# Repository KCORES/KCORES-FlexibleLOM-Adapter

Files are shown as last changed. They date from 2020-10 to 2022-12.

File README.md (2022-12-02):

# KCORES-FlexibleLOM-Adapter

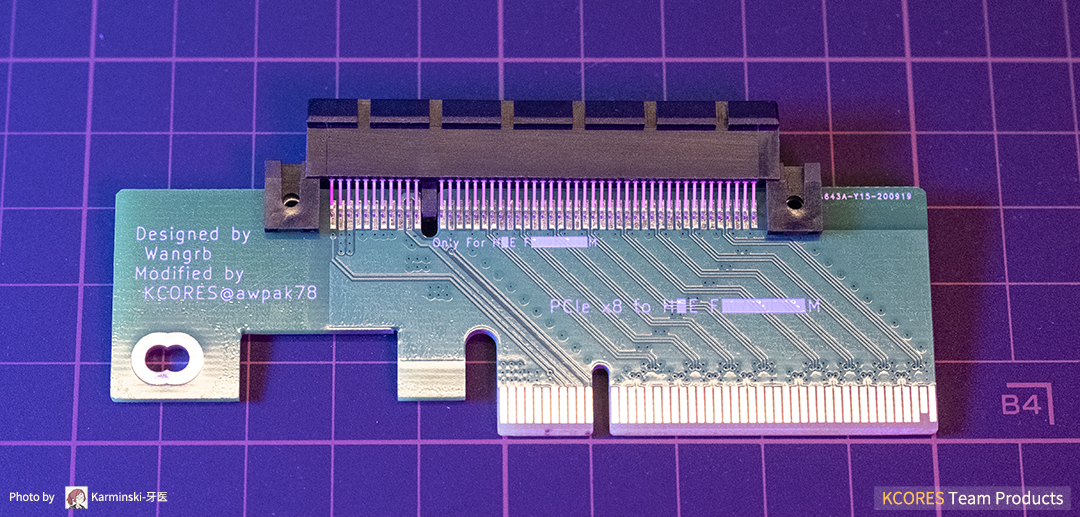
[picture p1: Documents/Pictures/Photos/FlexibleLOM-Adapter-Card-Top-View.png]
FlexibleLOM-Adapter-Card-Top-View
  

KCORES FlexibleLOM to PCIe x8 adapter and baffle model. The FLR series network cards can be used on normal motherboards PCIe slots, including common Gigabit, 10G, and 40G network cards. Due to size limitations, only full-height baffle design is available.  

KCORES FlexibleLOM 转 PCIe x8 转接卡开源设计，可以让普通电脑主板的 PCIe 槽使用 FLR 系列网卡，包括常见的千兆、万兆、40G网卡。由于尺寸限制，只提供全高挡板设计。

- 2 Layers PCB design, Easy to make  
双层PCB设计，容易制造

- Impedance matching by Polar SI9000  
使用 Polar SI9000 计算阻抗

- Size less than 10x10cm  
小尺寸，不超过 10x10cm

**[KCORES 官方网站](http://kcores.com/)**

**HomeLab 交流 QQ 群: 826702309**

# Compatibility

- ✔ Recommend 推荐
- 🟡 Compatible 兼容
- ❌ Fail 不兼容

| FlexibleLOM  | NIC Model | Connectors | [v1.0](https://github.com/KCORES/KCORES-FlexibleLOM-Adapter/releases/tag/v1.0) | v1.1 | SKU | SP | AS | Notes |
| --- | --- | --- | :----: | :----: | ---- | ---- | ---- | ---- |
| 331FLR | Broadcom BCM5719 | Quad RJ45 GbE | ❌ | ✔ | | | | 
| 366FLR | intel i350 | Quad RJ45 GbE | ✔ | ✔ | | | | 
| 530FLR-SFP+  | Broadcom BCM57810S | Dual SFP+ 10GbE | ❌ | ✔ | 647581-B21 | 649869-001 | 647579-001 |
| 533FLR-T | Broadcom BCM57810S | Dual RJ45 10GbE | ✔ | ✔ | 700759-B21 | 701534-001 | 700757-001 |
| 534FLR-SFP+  | Cavium BCM57810S | Dual SFP+ 10GbE | | | -B21 | -001 | -001 |
| 535FLR-T | Broadcom BCM57416 | Dual RJ45 10GbE | | | -B21 | -001 | -001 | RoCE V2, 15W |
| 536FLR-T | QLogic  57840S | Quad RJ45 10GbE | | | -B21 | -001 | -001 | 9W |
| 537FLR-SFP+  | Broadcom BCM57412 | Dual SFP+ 10GbE | | | -B21 | -001 | -001 | iWARP, 14W |
| ConnectX3ALOM| Mellanox ConnectX-3 | Single SFP+ 10GbE | | ✔ | 682148-B21 | 682625-001 | 682150-001 | 
| 544FLR-QSFP  | Mellanox ConnectX-3 | Dual QSFP+ 40GbE  | | | 649282-B21 | 656090-001 | 661686-001 |
| 544FLR-QSFP  | Mellanox ConnectX-3 | Dual QSFP+ 40GbE  | ✔ | ✔ | 649283-B21 | 656091-001 | 661687-001 |
| 544+FLR-SFP+ | Mellanox ConnectX-3 Pro | Single SFP+ 10GbE | ✔ | ✔ | 724206-B21 | 731850-001 | 724210-001 | 
| 544+FLR-QSFP | Mellanox ConnectX-3 Pro | Dual QSFP+ 40GbE  | ✔ | ✔ | 764285-B21 | 764737-001 | 764618-001 |
| 545FLR-QSFP  | Mellanox Connect-IB | Dual QSFP+ 56G IB | | | 7 -B21 | 7 -001 | 7 -001 |
| 546+FLR-SFP+ | Mellanox ConnectX-3 Pro | Dual SFP+ 10GbE | | | 779799-B21 | 7 -001 | 7 -001 |
| 547+FLR-QSFP | Mellanox ConnectX-5 | Dual QSFP+ 40GbE  | | | 879482-B21 | 8 -001 | 8 -001 |
| 554FLR-SFP+  | Emulex BE3 684213-B21 | Dual SFP+ 10GbE | | | 629142-B21 | 634026-001 | 629140-001 |
| 556FLR-T | Emulex XE-104 | Dual RJ45 10GbE | | | 794525-B21 | | | RoCE V1 |
| 556FLR-SFP+  | Emulex XE-102 727060-B21 | Dual SFP+ 10GbE | | | 732456-B21 | 764460-001 | 732454-001 | RoCE V1 |
| 560FLR-SFP+  | intel 82599 | Dual SFP+ 10GbE | ✔ | ✔ | | | | 
| 561FLR-T | intel X540 | Dual RJ45 10GbE | ✔ | ✔ | 700699-B21 | 701525-001 | 700697-001 |
| 562FLR-T | intel X550 | Dual RJ45 10GbE | ✔ | ✔ | 817745-B21 | 840138-001 | 817743 -001|
| 562FLR-SFP+  | intel X710 | Dual SFP+ 10GbE | | | 727054-B21 | 7 -001 | 7 -001 |
| 570FLR-SFP+  | SFC 9020 | Dual 10GbE | ✔ | ✔ | 717491-B21 | 717710-001 | 717489-001 | 

- **Note:**  
Some models of 544FLR-QSFP only support 10GbE and QDR. Please check
 the **Part Number** before buying!  
544FLR-QSFP 部分型号只支持 10GbE 和 QDR，请在购买前检查**物料号**！

# Directory

- /Documents/    
说明文档

- /Electricals/  
PCB design files  
3D 模型和挡板设计文件

- /Firmwares/  
Firmwares guide  
固件刷写相关教程

- /Mechanicals/  
FlexibleLOM Model and PCI Baffle  
FLR 卡模型及 PCI 挡板设计文件

# Photos & Renderings



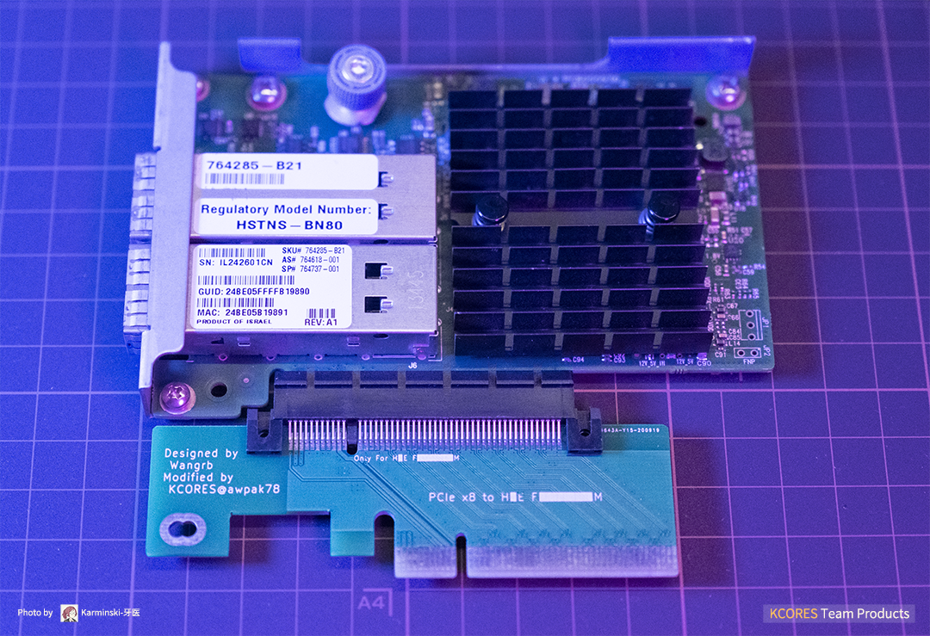
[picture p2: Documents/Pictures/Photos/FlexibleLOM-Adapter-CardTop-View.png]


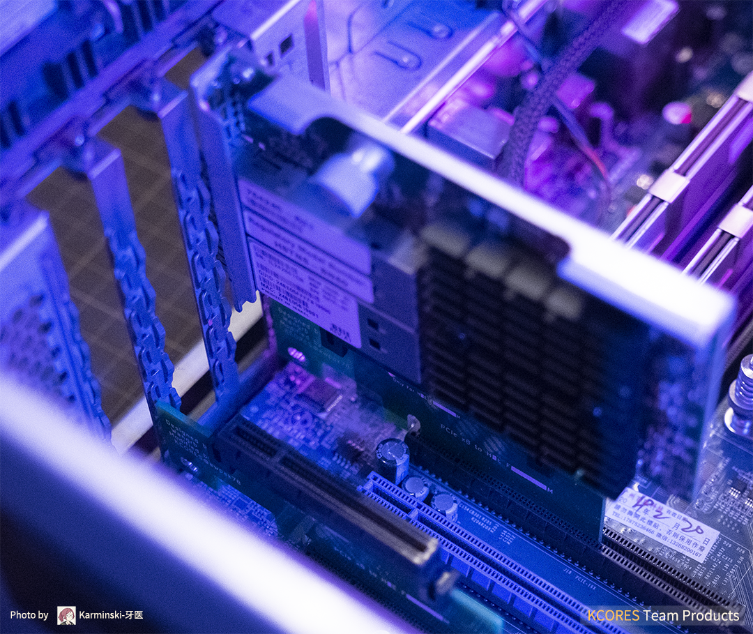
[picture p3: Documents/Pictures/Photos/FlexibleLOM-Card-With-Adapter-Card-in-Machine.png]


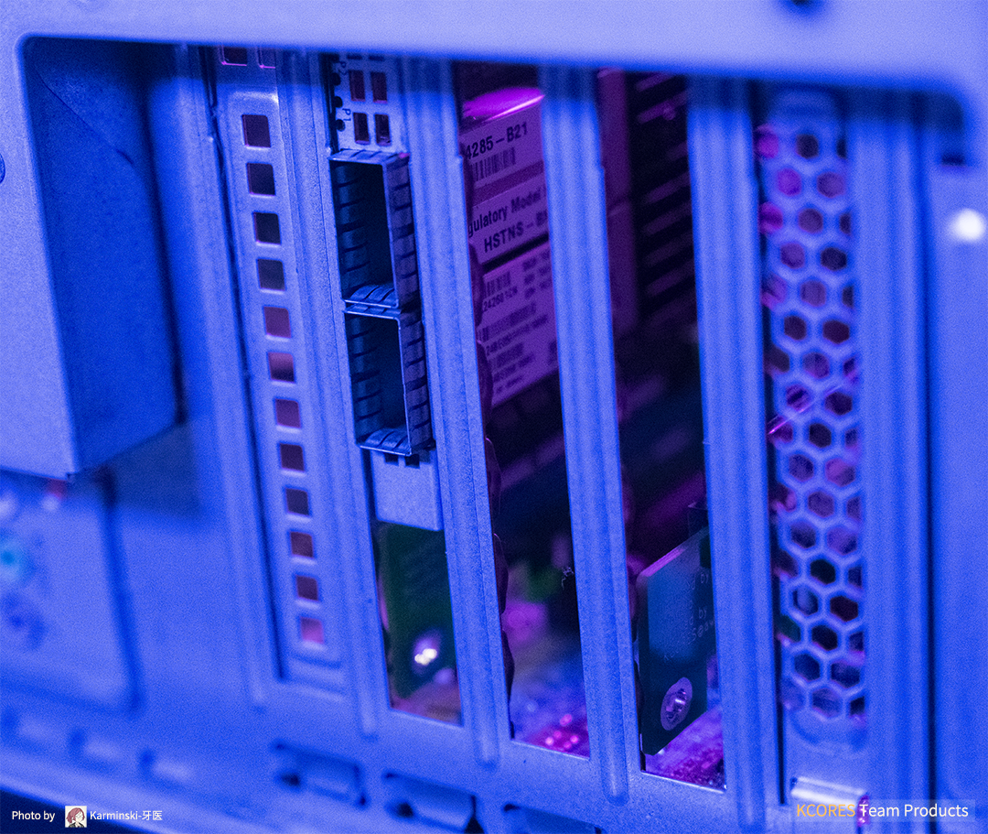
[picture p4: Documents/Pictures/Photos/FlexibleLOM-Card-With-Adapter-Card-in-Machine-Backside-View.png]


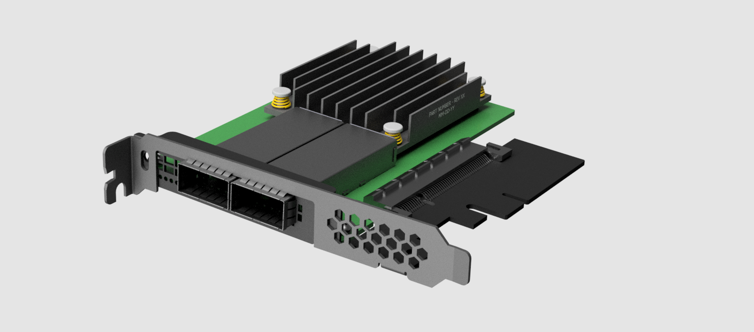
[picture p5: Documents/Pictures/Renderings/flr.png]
FlexibleLOM-Card-With-Adapter-Card-Renderings


# Thanks To

- [@Wangrb (Original Adapter Card Design)](https://github.com/Wangrb)
- [@AlphaArea (Main Contributer)](https://github.com/alphaarea)
- [@MistyMoonR (3D Model)](https://github.com/MistyMoonR)  
- [@Karminski (Photo)](https://github.com/karminski)

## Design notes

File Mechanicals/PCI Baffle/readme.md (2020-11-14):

# PCI Baffle

## Version: 1.0

- PCI Baffle Default  
  适合光口网卡  
  For SFP/QSFP Card  

- PCI Baffle RJ45  
  适合电口网卡   
  For RJ45 Crad

## Rendering   

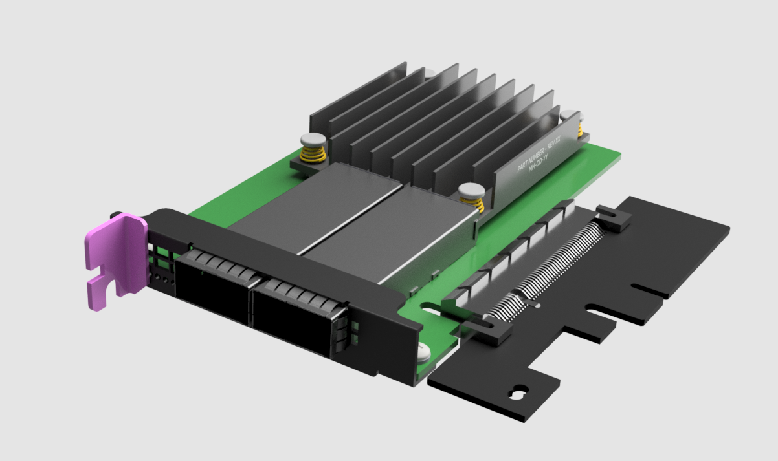
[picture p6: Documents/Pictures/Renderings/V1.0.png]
       

---

|Author |MistyMoon |
|--- |--- |
|E-mail |MistyMoonR@outlook.com |

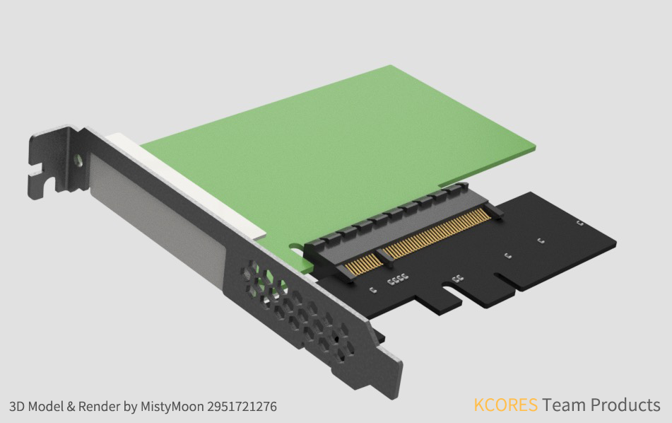
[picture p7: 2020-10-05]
Documents/Pictures/Photos/3D-Model.png

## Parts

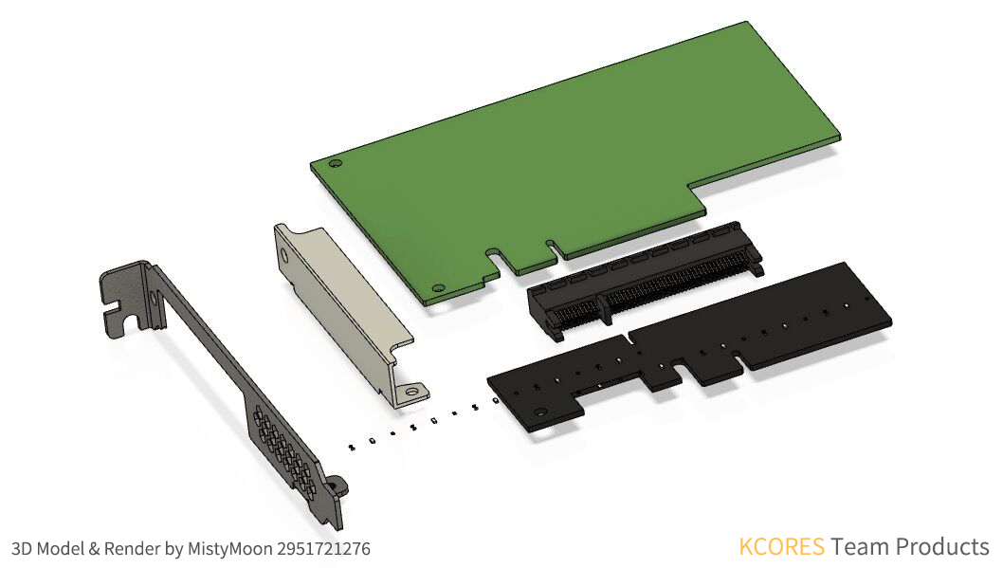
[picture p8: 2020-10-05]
Documents/Pictures/Photos/3D-Model-Parts.png

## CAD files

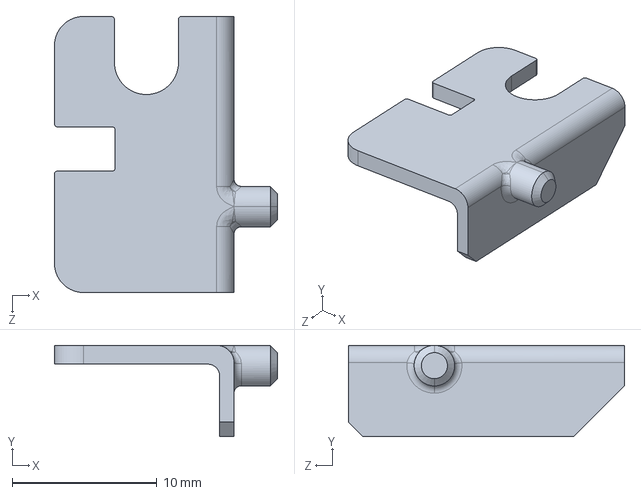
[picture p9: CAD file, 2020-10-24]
Mechanicals/PCI Baffle/PCI Baffle RJ45.STEP
15.4 x 6.30 x 19.1 mm

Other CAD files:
Mechanicals/PCI Baffle/PCI Baffle Default.STEP
Mechanicals/PCI Baffle/PCI Baffle Default.STL
Mechanicals/PCI Baffle/PCI Baffle RJ45.STL

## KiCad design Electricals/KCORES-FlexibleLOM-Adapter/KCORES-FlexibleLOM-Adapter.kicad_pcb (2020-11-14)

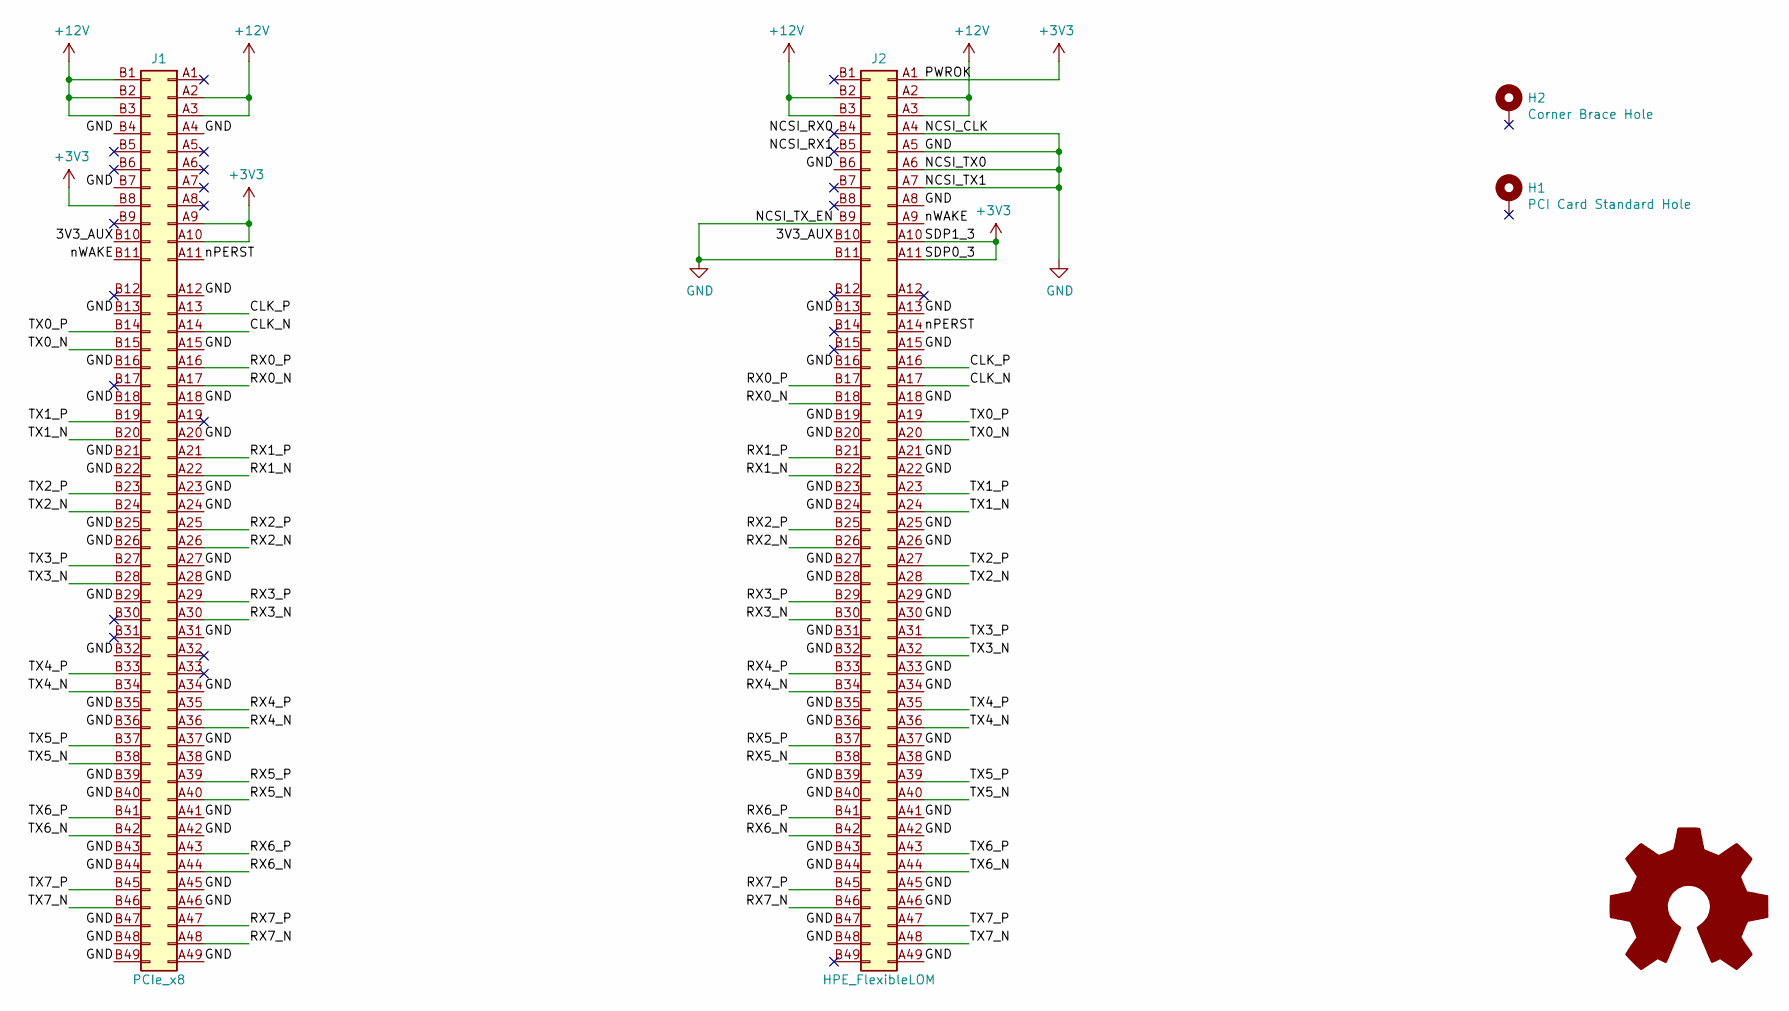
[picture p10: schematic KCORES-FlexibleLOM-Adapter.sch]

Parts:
H1: PCI Card Standard Hole; MountingHole_3.2mm_M3_Pad
H2: Corner Brace Hole; MountingHole_3.2mm_M3_Pad
J1: PCIe_x8; BUS_PCIexpress_x8
J2: HPE_FlexibleLOM; BUS_PCIexpress_x8_Straddle_Mount_Modify
LOGO1: Logo_Open_Hardware_Large; OSHW-Logo2_14.6x12mm_SilkScreen

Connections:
+3V3: J1.A9, J1.A10, J1.B8, J2.A1, J2.A10, J2.A11
+12V: J1.A2, J1.A3, J1.B1, J1.B2, J1.B3, J2.A2, J2.A3, J2.B2, J2.B3
/3V3_AUX: J1.B10, J2.B10
/CLK_N: J1.A14, J2.A17
/CLK_P: J1.A13, J2.A16
/NCSI_RX0: J2.B4
/NCSI_RX1: J2.B5
/RX0_N: J1.A17, J2.B18
/RX0_P: J1.A16, J2.B17
/RX1_N: J1.A22, J2.B22
/RX1_P: J1.A21, J2.B21
/RX2_N: J1.A26, J2.B26
/RX2_P: J1.A25, J2.B25
/RX3_N: J1.A30, J2.B30
/RX3_P: J1.A29, J2.B29
/RX4_N: J1.A36, J2.B34
/RX4_P: J1.A35, J2.B33
/RX5_N: J1.A40, J2.B38
/RX5_P: J1.A39, J2.B37
/RX6_N: J1.A44, J2.B42
/RX6_P: J1.A43, J2.B41
/RX7_N: J1.A48, J2.B46
/RX7_P: J1.A47, J2.B45
/TX0_N: J1.B15, J2.A20
/TX0_P: J1.B14, J2.A19
/TX1_N: J1.B20, J2.A24
/TX1_P: J1.B19, J2.A23
/TX2_N: J1.B24, J2.A28
/TX2_P: J1.B23, J2.A27
/TX3_N: J1.B28, J2.A32
/TX3_P: J1.B27, J2.A31
/TX4_N: J1.B34, J2.A36
/TX4_P: J1.B33, J2.A35
/TX5_N: J1.B38, J2.A40
/TX5_P: J1.B37, J2.A39
/TX6_N: J1.B42, J2.A44
/TX6_P: J1.B41, J2.A43
/TX7_N: J1.B46, J2.A48
/TX7_P: J1.B45, J2.A47
/nPERST: J1.A11, J2.A14
/nWAKE: J1.B11, J2.A9
GND: J1.A4, J1.A12, J1.A15, J1.A18, J1.A20, J1.A23, J1.A24, J1.A27, J1.A28, J1.A31, J1.A34, J1.A37, J1.A38, J1.A41, J1.A42, J1.A45, J1.A46, J1.A49, J1.B4, J1.B7, J1.B13, J1.B16, J1.B18, J1.B21, J1.B22, J1.B25, J1.B26, J1.B29, J1.B32, J1.B35, J1.B36, J1.B39, J1.B40, J1.B43, J1.B44, J1.B47, J1.B48, J1.B49, J2.A4, J2.A5, J2.A6, J2.A7, J2.A8, J2.A13, J2.A15, J2.A18, J2.A21, J2.A22, J2.A25, J2.A26, J2.A29, J2.A30, J2.A33, J2.A34, J2.A37, J2.A38, J2.A41, J2.A42, J2.A45, J2.A46, J2.A49, J2.B6, J2.B9, J2.B11, J2.B13, J2.B16, J2.B19, J2.B20, J2.B23, J2.B24, J2.B27, J2.B28, J2.B31, J2.B32, J2.B35, J2.B36, J2.B39, J2.B40, J2.B43, J2.B44, J2.B47, J2.B48

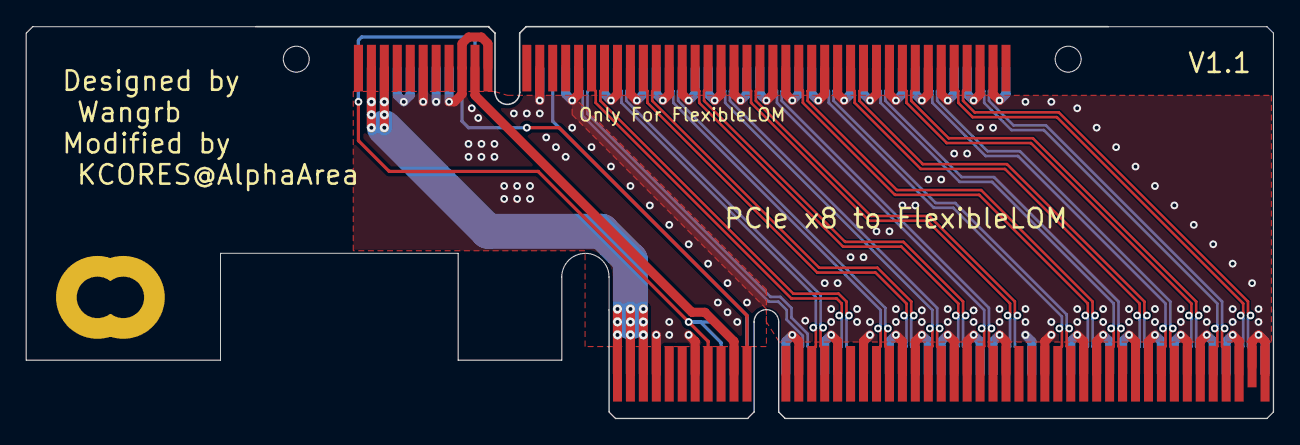
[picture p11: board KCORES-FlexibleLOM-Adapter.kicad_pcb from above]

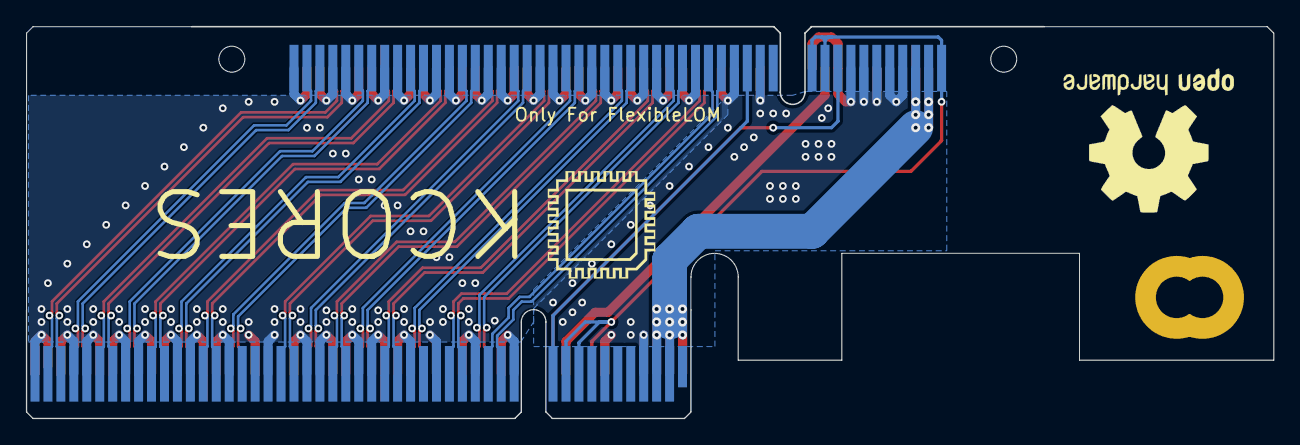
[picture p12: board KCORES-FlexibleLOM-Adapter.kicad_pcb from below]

Board: 2 copper layers, 96.3 x 30.2 mm, 5 parts (2 on the bottom side), 40 nets.

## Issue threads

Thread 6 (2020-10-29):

无法识别到卡

wodianw, 2020-10-29:
特定型号存在无法识别到卡
技嘉b360m-gamming
微星b360 b460
均无法识别，可能存在pcie插入检测

alphaarea, 2020-11-14:
v1.1 已修复 PRSNT 连接
https://github.com/KCORES/KCORES-FlexibleLOM-Adapter/commit/cd2b0448e99b53122162201c7c03747a536e690a

Closed 2020-11-14.

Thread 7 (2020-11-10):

沒看到gerber文件？

mlc130104, 2020-11-10:
```
/Gerber/
The current version of the gerber file
当前版本的 gerber 生产文件
```

請問一下是收起了來嗎？

alphaarea, 2020-11-11:
还没有发布Gerber文件，可以自己使用KiCAD导出

alphaarea, 2020-11-14:
在 Release 中放入了 gerber 文件
[KCORES FlexibleLOM Adapter V1.0](https://github.com/KCORES/KCORES-FlexibleLOM-Adapter/releases/tag/v1.0)

Closed 2020-11-13.

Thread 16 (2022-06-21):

STL bracket to secure cards

Dantali0n, 2022-06-21:
Hello I created a tiny STL for a 3d printable bracket that secures the card to the slots. You can find it here:

https://github.com/TobleMiner/HPE-FlexibleLOM-adapter/issues/11

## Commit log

2020-10-10 upload KiCAD project
    [KCORES-FlexibleLOM-Adapter.kicad_pcb, KCORES-FlexibleLOM-Adapter.sch]
2020-10-24 new PCI Baffle
    [FLR挡板 V0.1 bate.step, PCI Baffle Default.STEP, PCI Baffle Default.STL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]
2020-10-29 add step
    [BracketV2.step]
2020-11-13 Create V1 Branch
    [BracketV2.step]
2020-11-14 V1.0 Release
    [KCORES-FlexibleLOM-Adapter.kicad_pcb, KCORES-FlexibleLOM-Adapter.sch, PCI Baffle Default.STEP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]
